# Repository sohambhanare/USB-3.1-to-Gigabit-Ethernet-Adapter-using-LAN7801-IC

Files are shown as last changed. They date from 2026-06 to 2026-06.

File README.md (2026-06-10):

# USB-3.1-to-Gigabit-Ethernet-Adapter-using-LAN7801-IC
KiCad design of a USB 3.1 Gen 1 to Gigabit Ethernet adapter based on the LAN7801 and KSZ9031RNX. Includes schematic, 4-layer impedance-controlled PCB layout, power supply design, simulations, and manufacturing Gerbers.




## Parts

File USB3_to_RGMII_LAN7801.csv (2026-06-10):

Reference | Qty | Value | DNP | Exclude from BOM | Exclude from Board | Footprint | Datasheet
C1 | 1 | 10uF |  |  |  | Capacitor_SMD:C_0603_1608Metric | ~
C2 | 1 | 47uF |  |  |  | Capacitor_SMD:C_0603_1608Metric | ~
C3,C26 | 2 | 1uF |  |  |  | Capacitor_SMD:C_0603_1608Metric | ~
C4,C5,C6,C7,C8,C9,C10,C11,C12,C13,C14,C15,C17,C18,C19,C20,C21,C44 | 18 | 0.01uf |  |  |  | Capacitor_SMD:C_0603_1608Metric | ~
C16 | 1 | 22uf |  |  |  | Capacitor_SMD:C_0603_1608Metric | ~
C22,C23 | 2 | 0.1uF |  |  |  | Capacitor_SMD:C_0603_1608Metric | ~
C24,C25,C33,C49 | 4 | 22pF |  |  |  | Capacitor_SMD:C_0603_1608Metric | ~
C27,C43 | 2 | 1uf |  |  |  | Capacitor_SMD:C_0603_1608Metric | ~
C28,C29,C30,C31,C32,C34,C35,C36,C37,C38,C39,C40,C41,C42,C45,C46,C47,C48 | 18 | 0.1uf |  |  |  | Capacitor_SMD:C_0603_1608Metric | ~
J1 | 1 | USB3.1_A |  |  |  | Connector_USB:USB3_A_Molex_48393-001 | ~
J2 | 1 | RJ45_JK0654219 |  |  |  | Connector_RJ:RJ45_Pulse_JK0654219NL_Horizontal | https://media.digikey.com/pdf/Data%20Sheets/Pulse%20PDFs/JK%20Series.pdf
L1 | 1 | 3.3uh |  |  |  | Inductor_SMD:L_0603_1608Metric | ~
Q1 | 1 | Q_PMOS_DSG |  |  |  | Package_TO_SOT_SMD:SOT-23 | ~
R1 | 1 | 12k |  |  |  | Resistor_SMD:R_0603_1608Metric | ~
R2 | 1 | 2k |  |  |  | Resistor_SMD:R_0603_1608Metric | ~
R3,R4,R5,R6,R7,R23,R24,R25,R27,R28 | 10 | 10k |  |  |  | Resistor_SMD:R_0603_1608Metric | ~
R20 | 1 | 4.7k |  |  |  | Resistor_SMD:R_0603_1608Metric | ~
R21 | 1 | 1.5k |  |  |  | Resistor_SMD:R_0603_1608Metric | ~
R22 | 1 | 12.1k |  |  |  | Resistor_SMD:R_0603_1608Metric | ~
R26,R29,R30,R31 | 4 | 1k |  |  |  | Resistor_SMD:R_0603_1608Metric | ~
R32,R33 | 2 | 330 |  |  |  | Resistor_SMD:R_0603_1608Metric | ~
U1 | 1 | TPS7A4701xRGW |  |  |  | Package_DFN_QFN:Texas_RGW0020A_VQFN-20-1EP_5x5mm_P0.65mm_EP3.15x3.15mm_ThermalVias | https://www.ti.com/lit/ds/symlink/tps7a47.pdf
U2 | 1 | LAN7801T-I/9JX |  |  |  | LAN7801:VQFN64_9X9X0P9_R4_MCH | LAN7801T-I/9JX
U3 | 1 | 93LCxxB |  |  |  | Package_SO:SOIC-8_3.9x4.9mm_P1.27mm | http://ww1.microchip.com/downloads/en/DeviceDoc/20001749K.pdf
U4 | 1 | KSZ9031RNXCA |  |  |  | Package_DFN_QFN:QFN-48-1EP_7x7mm_P0.5mm_EP5.15x5.15mm | http://ww1.microchip.com/downloads/en/DeviceDoc/00002117C.pdf
U5 | 1 | TVS0500DRV |  |  |  | Package_SON:WSON-6-1EP_2x2mm_P0.65mm_EP1x1.6mm | http://www.ti.com/lit/ds/symlink/tvs0500.pdf
Y1,Y2 | 2 | 25MHz |  |  |  | Crystal:Crystal_SMD_3225-4Pin_3.2x2.5mm | ~

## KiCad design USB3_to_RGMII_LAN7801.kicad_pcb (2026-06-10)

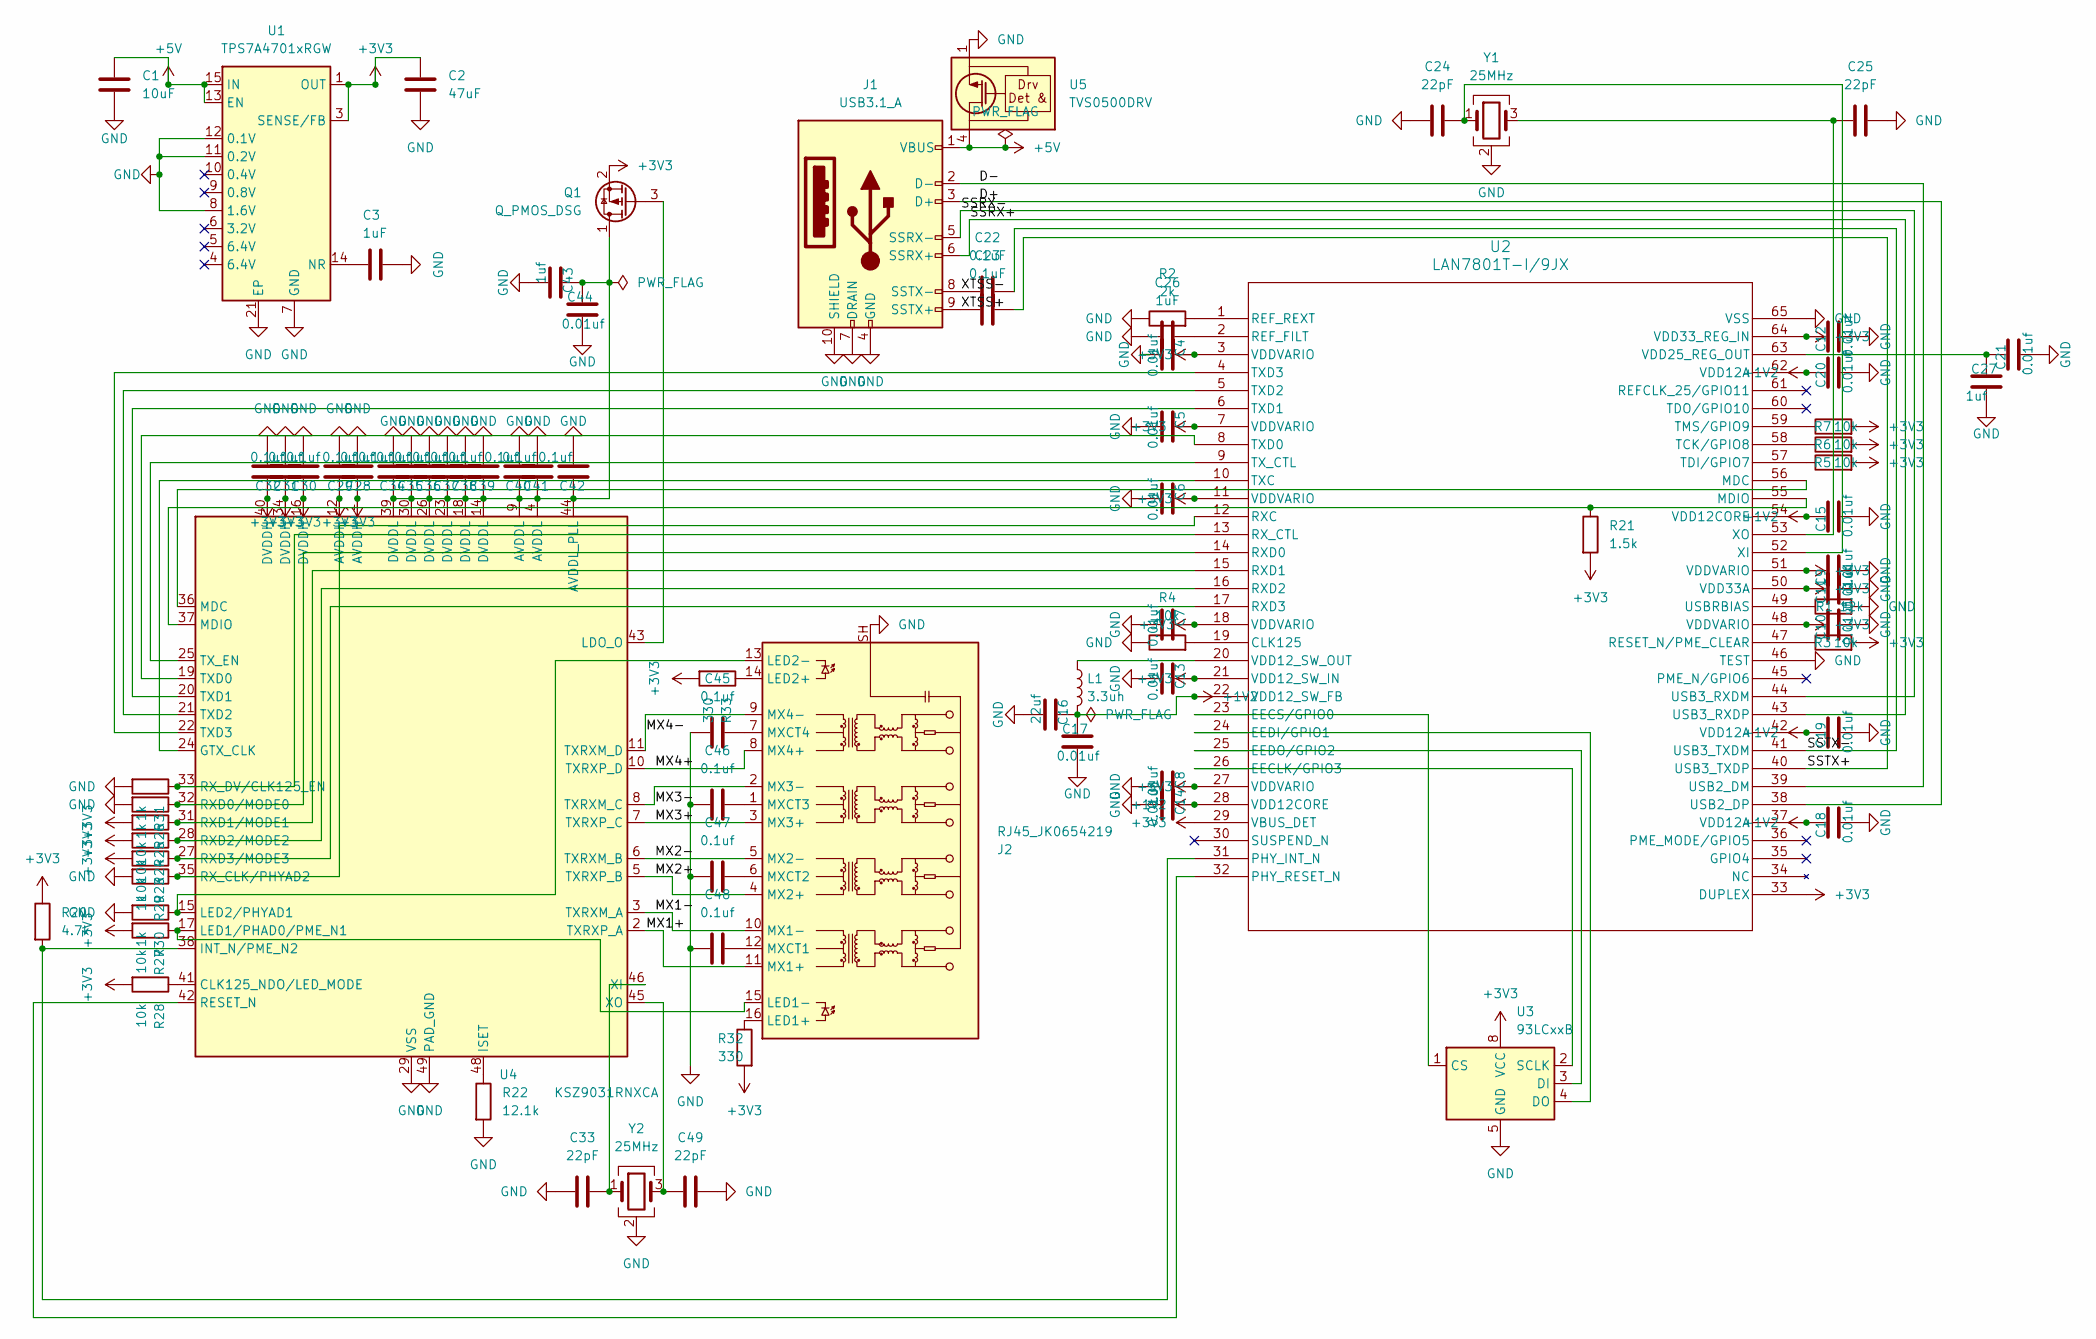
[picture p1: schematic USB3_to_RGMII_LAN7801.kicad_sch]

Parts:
C1: 10uF; C_0603_1608Metric
C2: 47uF; C_0603_1608Metric
C3, C26: 1uF; C_0603_1608Metric
C4, C5, C6, C7, C8, C9, C10, C11, C12, C13, C14, C15, C17, C18, C19, C20, C21, C44: 0.01uf; C_0603_1608Metric
C16: 22uf; C_0603_1608Metric
C22, C23: 0.1uF; C_0603_1608Metric
C24, C25, C33, C49: 22pF; C_0603_1608Metric
C27, C43: 1uf; C_0603_1608Metric
C28, C29, C30, C31, C32, C34, C35, C36, C37, C38, C39, C40, C41, C42, C45, C46, C47, C48: 0.1uf; C_0603_1608Metric
J1: USB3.1_A; USB3_A_Molex_48393-001
J2: RJ45_JK0654219; RJ45_Pulse_JK0654219NL_Horizontal
L1: 3.3uh; L_0603_1608Metric
Q1: Q_PMOS_DSG; SOT-23
R1: 12k; R_0603_1608Metric
R2: 2k; R_0603_1608Metric
R3, R4, R5, R6, R7, R23, R24, R25, R27, R28: 10k; R_0603_1608Metric
R20: 4.7k; R_0603_1608Metric
R21: 1.5k; R_0603_1608Metric
R22: 12.1k; R_0603_1608Metric
R26, R29, R30, R31: 1k; R_0603_1608Metric
R32, R33: 330; R_0603_1608Metric
U1: TPS7A4701xRGW; Texas_RGW0020A_VQFN-20-1EP_5x5mm_P0.65mm_EP3.15x3.15mm_Ther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
U2: LAN7801T-I/9JX; VQFN64_9X9X0P9_R4_MCH
U3: 93LCxxB; SOIC-8_3.9x4.9mm_P1.27mm
U4: KSZ9031RNXCA; QFN-48-1EP_7x7mm_P0.5mm_EP5.15x5.15mm
U5: TVS0500DRV; WSON-6-1EP_2x2mm_P0.65mm_EP1x1.6mm
Y1, Y2: 25MHz; Crystal_SMD_3225-4Pin_3.2x2.5mm

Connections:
+1V2: C14.1, C15.1, C16.1, C17.1, C18.1, C19.1, C20.1, L1.2, U2.22 (VDD12_SW_FB), U2.28 (VDD12CORE), U2.37 (VDD12A), U2.42 (VDD12A), U2.54 (VDD12CORE), U2.62 (VDD12A)
+3V3: C2.1, C4.1, C5.1, C6.1, C7.1, C8.1, C9.1, C10.1, C11.1, C12.1, C13.1, C28.1, C29.1, C30.1, C31.1, C32.1, Q1.2 (S), R3.2, R5.2, R6.2, R7.2, R20.1, R21.2, R23.2, R24.2, R25.2, R27.2, R28.2, R32.2, R33.2, U1.1 (OUT), U1.3 (SENSE/FB), U1.20 (OUT), U2.3 (VDDVARIO), U2.7 (VDDVARIO), U2.11 (VDDVARIO), U2.18 (VDDVARIO), U2.21 (VDD12_SW_IN), U2.27 (VDDVARIO), U2.29 (VBUS_DET), U2.33 (DUPLEX), U2.48 (VDDVARIO), U2.50 (VDD33A), U2.51 (VDDVARIO), U2.64 (VDD33_REG_IN), U3.8 (VCC), U4.1 (AVDDH), U4.12 (AVDDH), U4.16 (DVDDH), U4.34 (DVDDH), U4.40 (DVDDH)
+5V: C1.1, J1.1 (VBUS), U1.13 (EN), U1.15 (IN), U1.16 (IN), U5.4 (IN), U5.5 (IN), U5.6 (IN)
/D+: J1.3 (D+), U2.38 (USB2_DP)
/D-: J1.2 (D-), U2.39 (USB2_DM)
/MX1+: J2.11 (MX1+), U4.2 (TXRXP_A)
/MX1-: J2.10 (MX1-), U4.3 (TXRXM_A)
/MX2+: J2.4 (MX2+), U4.5 (TXRXP_B)
/MX2-: J2.5 (MX2-), U4.6 (TXRXM_B)
/MX3+: J2.3 (MX3+), U4.7 (TXRXP_C)
/MX3-: J2.2 (MX3-), U4.8 (TXRXM_C)
/MX4+: J2.8 (MX4+), U4.10 (TXRXP_D)
/MX4-: J2.9 (MX4-), U4.11 (TXRXM_D)
/SSRX+: J1.6 (SSRX+), U2.43 (USB3_RXDP)
/SSRX-: J1.5 (SSRX-), U2.44 (USB3_RXDM)
/SSTX+: C23.2, U2.40 (USB3_TXDP)
/SSTX-: C22.2, U2.41 (USB3_TXDM)
/XTSS+: C23.1, J1.9 (SSTX+)
/XTSS-: C22.1, J1.8 (SSTX-)
GND: C1.2, C2.2, C3.2, C4.2, C5.2, C6.2, C7.2, C8.2, C9.2, C10.2, C11.2, C12.2, C13.2, C14.2, C15.2, C16.2, C17.2, C18.2, C19.2, C20.2, C21.2, C24.1, C25.2, C26.1, C27.2, C28.2, C29.2, C30.2, C31.2, C32.2, C33.1, C34.2, C35.2, C36.2, C37.2, C38.2, C39.2, C40.2, C41.2, C42.2, C43.2, C44.2, C45.1, C46.1, C47.1, C48.1, C49.2, J1.4 (GND), J1.7 (DRAIN), J1.10 (SHIELD), J2.SH, R1.2, R2.1, R4.1, R22.2, R26.2, R29.2, R30.2, R31.2, U1.7 (GND), U1.8 (1.6V), U1.11 (0.2V), U1.12 (0.1V), U1.21 (EP), U2.46 (TEST), U2.65 (VSS), U3.5 (GND), U4.29 (VSS), U4.49 (PAD_GND), U5.1 (GND), U5.2 (GND), U5.3 (GND), U5.7 (GND), Y1.2 (G), Y1.4 (G), Y2.2 (G), Y2.4 (G)
unnamed: J2.16 (LED1+), R32.1
unnamed: J2.15 (LED1-), R27.1, U4.17 (LED1/PHAD0/PME_N1)
unnamed: J2.14 (LED2+), R33.1
unnamed: J2.13 (LED2-), R30.1, U4.15 (LED2/PHYAD1)
unnamed: C48.2, J2.12 (MXCT1)
unnamed: C47.2, J2.6 (MXCT2)
unnamed: C46.2, J2.1 (MXCT3)
unnamed: C45.2, J2.7 (MXCT4)
unnamed: C34.1, C35.1, C36.1, C37.1, C38.1, C39.1, C40.1, C41.1, C42.1, C43.1, C44.1, Q1.1 (D), U4.4 (AVDDL), U4.9 (AVDDL), U4.14 (DVDDL), U4.18 (DVDDL), U4.23 (DVDDL), U4.26 (DVDDL), U4.30 (DVDDL), U4.39 (DVDDL), U4.44 (AVDDL_PLL)
unnamed: Q1.3 (G), U4.43 (LDO_O)
unnamed: C3.1, U1.14 (NR)
unnamed: R4.2, U2.19 (CLK125)
unnamed: U2.26 (EECLK/GPIO3), U3.2 (SCLK)
unnamed: U2.23 (EECS/GPIO0), U3.1 (CS)
unnamed: U2.24 (EEDI/GPIO1), U3.4 (DO)
unnamed: U2.25 (EEDO/GPIO2), U3.3 (DI)
unnamed: U2.56 (MDC), U4.36 (MDC)
unnamed: R21.1, U2.55 (MDIO), U4.37 (MDIO)
unnamed: R20.2, U2.31 (PHY_INT_N), U4.38 (INT_N/PME_N2)
unnamed: U2.32 (PHY_RESET_N), U4.42 (RESET_N)
unnamed: C26.2, U2.2 (REF_FILT)
unnamed: R2.2, U2.1 (REF_REXT)
unnamed: R3.1, U2.47 (RESET_N/PME_CLEAR)
unnamed: R29.1, U2.12 (RXC), U4.35 (RX_CLK/PHYAD2)
unnamed: R26.1, U2.14 (RXD0), U4.32 (RXD0/MODE0)
unnamed: R25.1, U2.15 (RXD1), U4.31 (RXD1/MODE1)
unnamed: R24.1, U2.16 (RXD2), U4.28 (RXD2/MODE2)
unnamed: R23.1, U2.17 (RXD3), U4.27 (RXD3/MODE3)
unnamed: R31.1, U2.13 (RX_CTL), U4.33 (RX_DV/CLK125_EN)
unnamed: R6.1, U2.58 (TCK/GPIO8)
unnamed: R5.1, U2.57 (TDI/GPIO7)
unnamed: R7.1, U2.59 (TMS/GPIO9)
unnamed: U2.10 (TXC), U4.24 (GTX_CLK)
unnamed: U2.8 (TXD0), U4.19 (TXD0)
unnamed: U2.6 (TXD1), U4.20 (TXD1)
unnamed: U2.5 (TXD2), U4.21 (TXD2)
unnamed: U2.4 (TXD3), U4.22 (TXD3)
unnamed: U2.9 (TX_CTL), U4.25 (TX_EN)
unnamed: R1.1, U2.49 (USBRBIAS)
unnamed: L1.1, U2.20 (VDD12_SW_OUT)
unnamed: C21.1, C27.1, U2.63 (VDD25_REG_OUT)
unnamed: C24.2, U2.52 (XI), Y1.1
unnamed: C25.1, U2.53 (XO), Y1.3
unnamed: R28.1, U4.41 (CLK125_NDO/LED_MODE)
unnamed: R22.1, U4.48 (ISET)
unnamed: C33.2, U4.46 (XI), Y2.1
unnamed: C49.1, U4.45 (XO), Y2.3

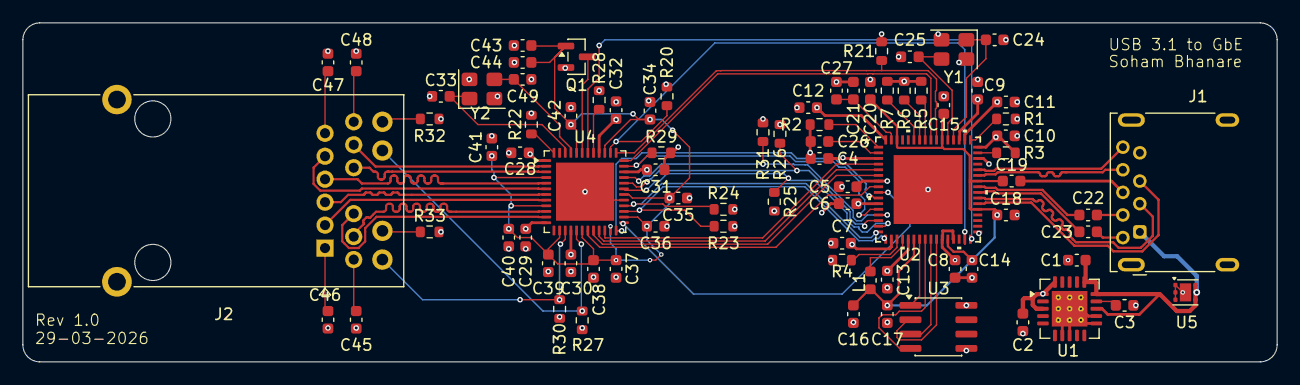
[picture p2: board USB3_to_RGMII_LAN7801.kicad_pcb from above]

Board: 4 copper layers, 111.0 x 30.0 mm, 81 parts (0 on the bottom side), 67 nets.
